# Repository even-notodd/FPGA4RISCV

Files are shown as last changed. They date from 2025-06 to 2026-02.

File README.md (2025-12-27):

# FPGA4RISCV
This project is an attempt to build hardware (SOM and baseboard) capable of runnig Linux on RISCV MCU implemented in FPGA.
## This is work in progress, not finished project (!).
Overview: 

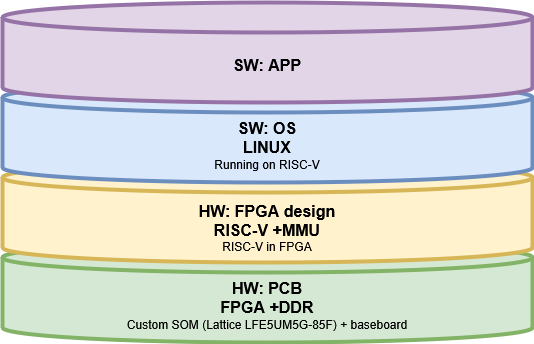
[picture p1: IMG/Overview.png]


[Edit this diagram](https://app.diagrams.net/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)

# SOM
SOM is supposed to be designed in a format of a SO-DIMM card (Small Outline Dual Inline Memory Module) with standard 200 pin board edge connector.
SoM is based on Lattice FPGA chip LFE5UM5G-85F with dedicated DDR3 memory.

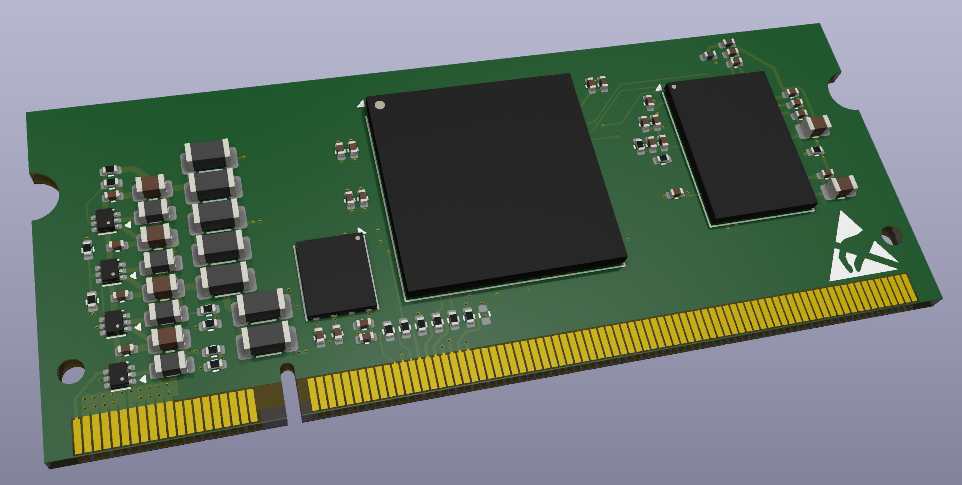
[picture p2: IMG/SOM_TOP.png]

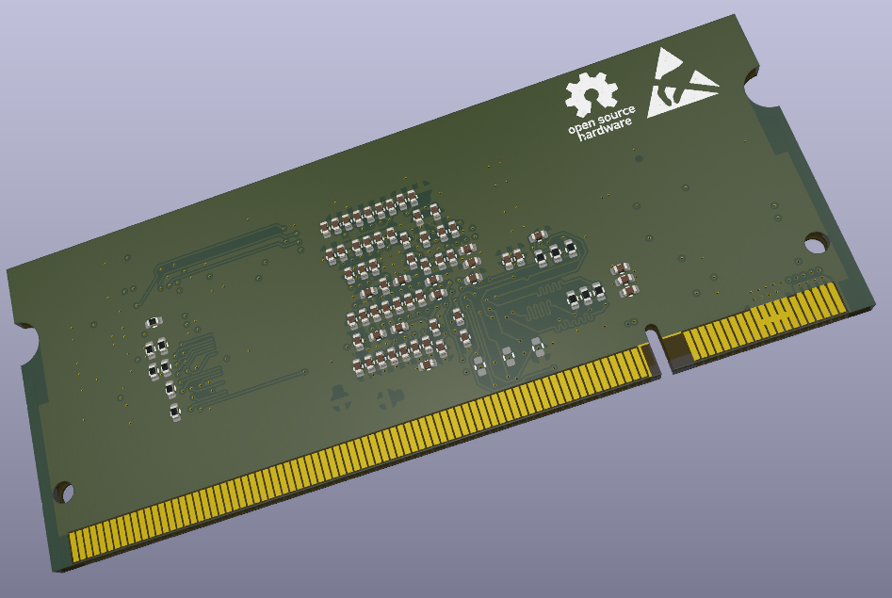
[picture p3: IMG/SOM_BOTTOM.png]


# Baseboard
Baseboard is supposed to be more or less generic baseboard and planned to be used with other SoMs. Concequently it must have:
- Power supply with several standard voltages
- Ethernet Phy
- USB 2.0 Phy & USB Hub
- USB 3.0
- PCIe
- USB-JTAG
- USB-UART
- GPIO headers
- UART/I2C/SPI headers
- HDMI

## License
See the LICENSE file for details.

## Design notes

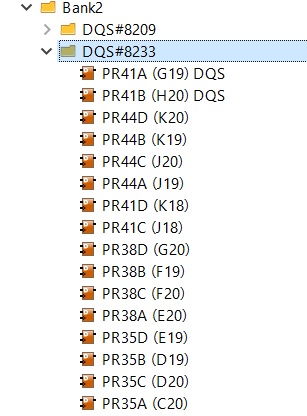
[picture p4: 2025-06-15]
IMG/DDR-Bank2.jpg

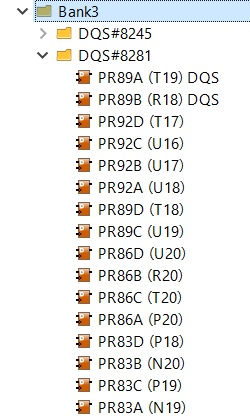
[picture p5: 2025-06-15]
IMG/DDR-Bank3.jpg

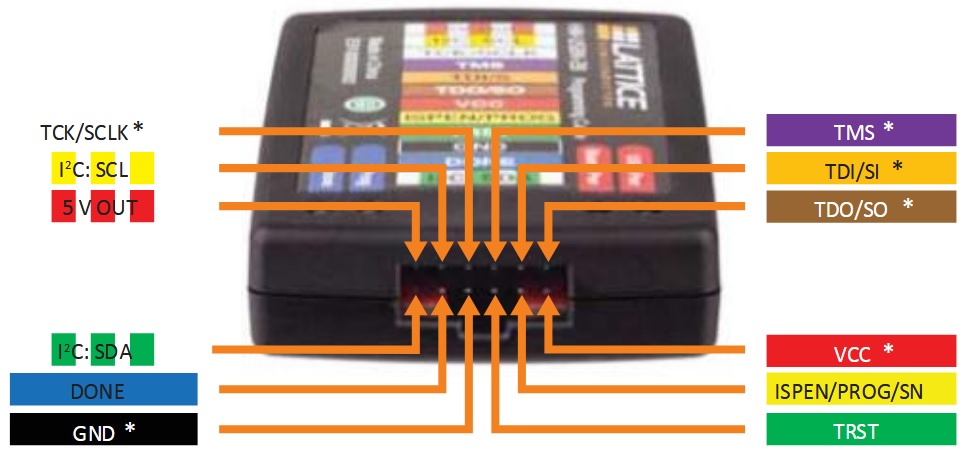
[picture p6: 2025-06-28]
IMG/Untitled.jpg

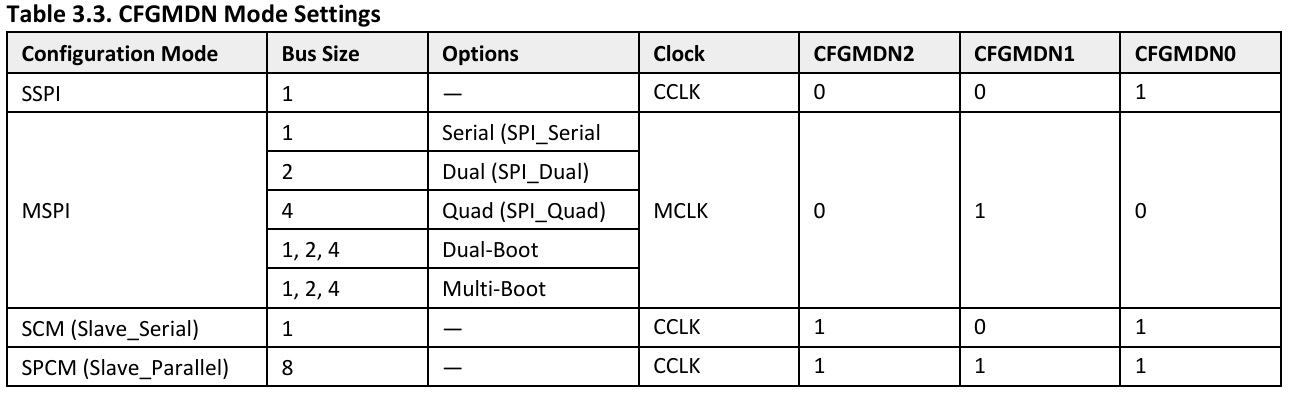
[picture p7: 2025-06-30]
IMG/Boot_CFG.jpg

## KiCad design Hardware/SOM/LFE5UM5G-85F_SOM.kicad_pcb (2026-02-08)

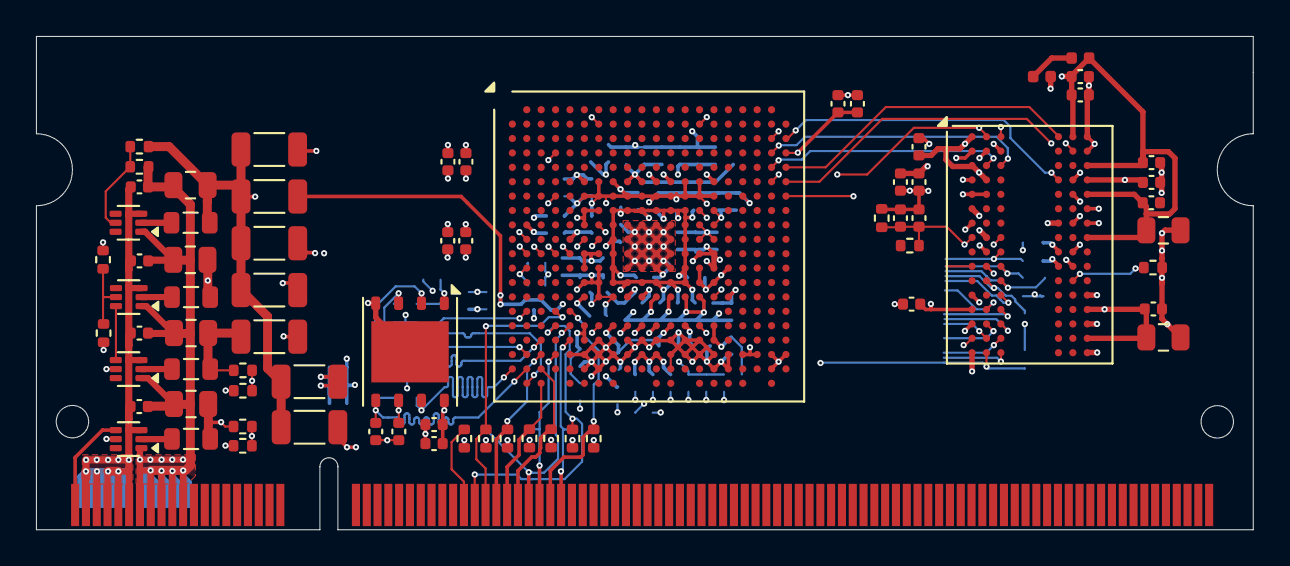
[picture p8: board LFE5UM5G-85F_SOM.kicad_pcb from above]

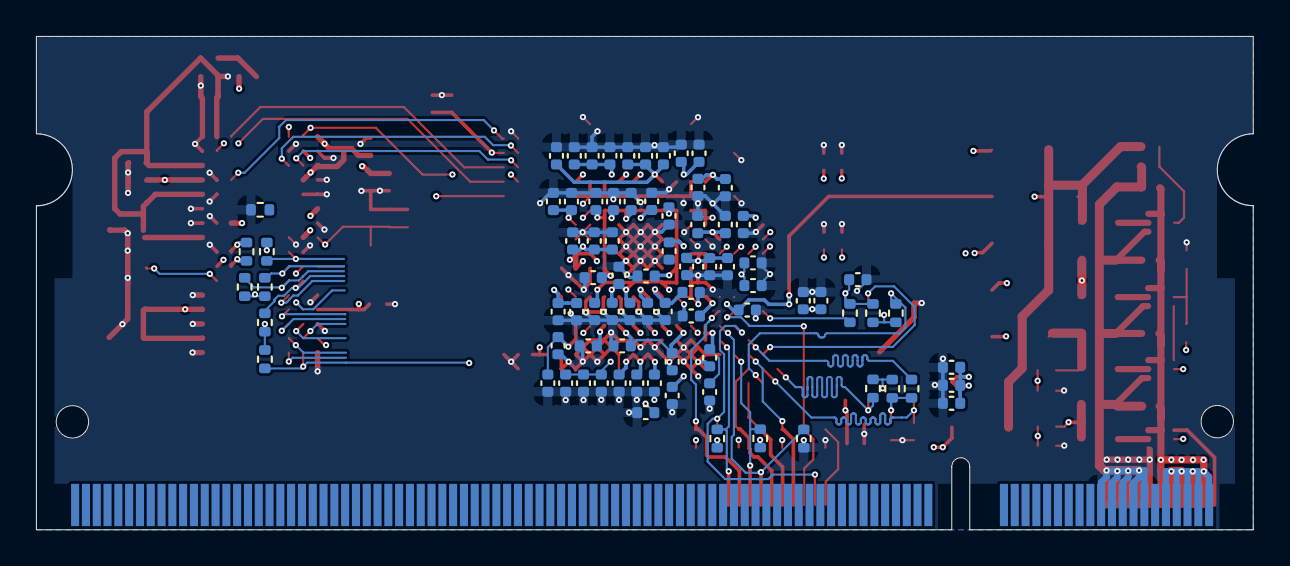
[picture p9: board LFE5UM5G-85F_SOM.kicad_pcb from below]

Board: 8 copper layers, 67.6 x 27.4 mm, 151 parts (80 on the bottom side), 94 nets.

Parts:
C1, C2, C3, C4, C5, C6, C7, C8, C9, C13, C14, C15, C17, C18, C19, C21, C22, C23, C27, C28, C30, C31, C32, C34, C46, C47, C48, C49, C50, C51, C52, C53, C54, C64, C65, C66, C67, C68, C69, C71, C73, C75, C76, C77, C84, C85, C86, C87, C89, C93: 100nF; C_0402_1005Metric
C10, C11, C12, C24, C26, C35, C36, C38, C39, C40, C41, C42, C56, C57, C58, C59, C63, C94, C95, C96, C99, C100: 10uF; C_0402_1005Metric
C43, C44, C45, C55, C60, C61, C62, C70, C72, C74, C80, C81, C82, C83, C88: 1uF; C_0402_1005Metric
C78, C79, C97, C98, C101, C102: 22uF; C_0805_2012Metric
C90, C91, C92: 22pF; C_0402_1005Metric
FB1, FB2, FB3, FB4, FB5, FB6, FB7: FerriteBead; L_1206_3216Metric
FB8, FB9: FerriteBead; L_0402_1005Metric
J1: SODIMM-200_Split; SODIMM-200_1.8V_Card_edge
L1, L2, L3, L4: 1uH; L_0805_2012Metric
R1: 100R; R_0402_1005Metric
R2, R3, R4, R5, R6, R7, R25, R26, R27, R28, R29, R30: 10K; R_0402_1005Metric
R8: 240R; R_0402_1005Metric
R9, R10: 1K; R_0402_1005Metric
R11: 49.9R; R_0402_1005Metric
R12, R14, R16: 4k7; R_0402_1005Metric
R13: 0R; R_0402_1005Metric
R15: 1k; R_0402_1005Metric
R17: 442k; R_0402_1005Metric
R18, R20, R22, R23, R24: 100K; R_0402_1005Metric
R19: 316k; R_0402_1005Metric
R21: 150k; R_0402_1005Metric
R31, R32, R33, R34: 4.7k; R_0402_1005Metric
U1: LFE5UM5G-85F; Lattice_caBGA-381_17x17mm_Layout20x20_P0.8mm
U2: AS4C256M16D3; BGA-96_9.0x13.0mm_Layout2x3x16_P0.8mm
U3: W25Q128JVP; WSON-8-1EP_6x5mm_P1.27mm_EP3.4x4.3mm
U4, U5, U6, U7: TPS62A02ADRL; SOT-563

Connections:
1.2V: C1.2, C5.2, C9.2, C13.2, C14.2, C18.2, C22.2, C23.2, C27.2, C31.2, C35.2, C39.2, C102.2, FB1.1, FB2.1, FB3.1, FB5.1, FB6.1, FB7.1, L4.2, R23.2, U1.H8 (VCC), U1.H9 (VCC), U1.H10 (VCC), U1.H11 (VCC), U1.H12 (VCC), U1.H13 (VCC), U1.J8 (VCC), U1.J13 (VCC), U1.K8 (VCC), U1.K13 (VCC), U1.L8 (VCC), U1.L13 (VCC), U1.M8 (VCC), U1.M13 (VCC), U1.N8 (VCC), U1.N9 (VCC), U1.N10 (VCC), U1.N11 (VCC), U1.N12 (VCC), U1.N13 (VCC)
1.5V: C2.2, C3.2, C4.2, C6.2, C7.2, C8.2, C10.2, C11.2, C12.2, C28.2, C32.2, C36.2, C101.2, FB8.1, FB9.1, L3.2, R9.2, R21.2, U1.F9 (VCCIO0), U1.F10 (VCCIO0), U1.H14 (VCCIO2), U1.H15 (VCCIO2), U1.J15 (VCCIO2), U1.L6 (VCCIO6), U1.L7 (VCCIO6), U1.L14 (VCCIO3), U1.L15 (VCCIO3), U1.M6 (VCCIO6), U1.M15 (VCCIO3)
2.5V: C98.2, FB4.1, L2.2, R19.2
2.5V_A: C46.2, C50.2, C54.2, C55.2, C59.2, C63.2, FB4.2, U1.F6 (VCCAUX), U1.F15 (VCCAUX), U1.P6 (VCCAUX), U1.P15 (VCCAUX), U1.V10 (VCCAUXA0), U1.V11 (VCCAUXA0), U1.V17 (VCCAUXA1), U1.V18 (VCCAUXA1)
3.3V: C15.2, C17.2, C19.2, C21.2, C24.2, C26.2, C30.2, C34.2, C38.2, C93.2, C94.2, C97.2, L1.2, R12.1, R14.1, R15.1, R16.1, R17.2, R25.1, R26.1, R27.1, R28.1, R31.2, R32.2, R33.2, U1.F11 (VCCIO1), U1.F12 (VCCIO1), U1.H6 (VCCIO7), U1.H7 (VCCIO7), U1.J6 (VCCIO7), U1.P9 (VCCIO8), U1.P10 (VCCIO8), U3.8 (VCC)
5V: C95.2, C96.2, C99.2, C100.2, J1.2, J1.3, J1.4, J1.5, J1.6, J1.7, J1.8, J1.9, J1.10, J1.11, U4.3 (VIN), U5.3 (VIN), U6.3 (VIN), U7.3 (VIN)
/DDR/ZQ: R8.1, U2.L8 (ZQ)
/Power Supply/1.5V_PG: U5.4 (EN), U6.6 (PG), U7.4 (EN)
BB_PGOOD: J1.1, U4.4 (EN), U6.4 (EN)
BOOT_MODE_0: J1.61, R30.2, U1.U4 (CFG_0)
BOOT_MODE_1: J1.63, R28.2, U1.T4 (CFG_1)
BOOT_MODE_2: J1.65, R29.2, U1.R4 (CFG_2)
DDR_A0: U1.L20 (PR47A), U2.N3 (A0)
DDR_A1: U1.M20 (PR47B), U2.P7 (A1)
DDR_A2: U1.L19 (PR47C), U2.P3 (A2)
DDR_A3: U1.M19 (PR47D), U2.N2 (A3)
DDR_A4: U1.L16 (PR50A), U2.P8 (A4)
DDR_A5: U1.L17 (PR50B), U2.P2 (A5)
DDR_A6: U1.L18 (PR50C), U2.R8 (A6)
DDR_A7: U1.M18 (PR50D), U2.R2 (A7)
DDR_A8: U1.N18 (PR53C), U2.T8 (A8)
DDR_A9: U1.P17 (PR53D), U2.R3 (A9)
DDR_A10: U1.C18 (PR11A), U2.L7 (A10/AP)
DDR_A11: U1.D17 (PR11B), U2.R7 (A11)
DDR_A12: U1.E16 (PR11C), U2.N7 (A12/~BC)
DDR_A13: U1.F16 (PR11D), U2.T3 (A13)
DDR_A14: U1.D18 (PR14A), U2.T7 (A14)
DDR_BA0: U1.E17 (PR14B), U2.M2 (BA0)
DDR_BA1: U1.E18 (PR14C), U2.N8 (BA1)
DDR_BA2: U1.F18 (PR14D), U2.M3 (BA2)
DDR_CAS: R6.1, U1.J17 (PR20C), U2.K3 (~CAS)
DDR_CKE: U1.G16 (PR17C), U2.K9 (CKE)
DDR_CK_N: R1.2, U1.G18 (PR17B), U2.K7 (~CK)
DDR_CK_P: R1.1, U1.F17 (PR17A), U2.J7 (CK)
DDR_CS: R4.1, U1.H18 (PR20A), U2.L2 (~CS)
DDR_DQ0: U1.N19 (PR83A), U2.E3 (DQ0)
DDR_DQ1: U1.N20 (PR83B), U2.F7 (DQ1)
DDR_DQ2: U1.P19 (PR83C), U2.F2 (DQ2)
DDR_DQ3: U1.P18 (PR83D), U2.F8 (DQ3)
DDR_DQ4: U1.P20 (PR86A), U2.H3 (DQ4)
DDR_DQ5: U1.R20 (PR86B), U2.H8 (DQ5)
DDR_DQ6: U1.T20 (PR86C), U2.G2 (DQ6)
DDR_DQ7: U1.U20 (PR86D), U2.H7 (DQ7)
DDR_DQ8: U1.C20 (PR35A), U2.D7 (DQ8)
DDR_DQ9: U1.D19 (PR35B), U2.C3 (DQ9)
DDR_DQ10: U1.K18 (PR41D), U2.C8 (DQ10)
DDR_DQ11: U1.E19 (PR35D), U2.C2 (DQ11)
DDR_DQ12: U1.E20 (PR38A), U2.A7 (DQ12)
DDR_DQ13: U1.F19 (PR38B), U2.A2 (DQ13)
DDR_DQ14: U1.F20 (PR38C), U2.B8 (DQ14)
DDR_DQ15: U1.G20 (PR38D), U2.A3 (DQ15)
DDR_LDM: U1.U19 (PR89C), U2.E7 (LDM)
DDR_LDQS_N: U1.R18 (PR89B), U2.G3 (~LDQS)
DDR_LDQS_P: U1.T19 (PR89A), U2.F3 (LDQS)
DDR_ODT: R2.1, U1.K16 (PR29A), U2.K1 (ODT)
DDR_RAS: R5.1, U1.H17 (PR20B), U2.J3 (~RAS)
DDR_RST: R3.1, U1.H16 (PR17D), U2.T2 (~RESET)
DDR_UDM: U1.J18 (PR41C), U2.D3 (UDM)
DDR_UDQS_N: U1.H20 (PR41B), U2.B7 (~UDQS)
DDR_UDQS_P: U1.G19 (PR41A), U2.C7 (UDQS)
DDR_VDDQ_1.5V: C76.2, C78.2, C80.2, C82.2, C84.2, C86.2, FB8.2, U2.A1 (VDDQ), U2.A8 (VDDQ), U2.C1 (VDDQ), U2.C9 (VDDQ), U2.D2 (VDDQ), U2.E9 (VDDQ), U2.F1 (VDDQ), U2.H2 (VDDQ), U2.H9 (VDDQ)
DDR_VDD_1.5V: C77.2, C79.2, C81.2, C83.2, C85.2, C87.2, FB9.2, R3.2, R4.2, R5.2, R6.2, R7.2, U2.B2 (VDD), U2.D9 (VDD), U2.G7 (VDD), U2.K2 (VDD), U2.K8 (VDD), U2.N1 (VDD), U2.N9 (VDD), U2.R1 (VDD), U2.R9 (VDD)
DDR_VREF: C70.2, C71.2, C72.2, C73.2, C74.2, C75.2, C88.2, C89.2, R9.1, R10.2, U1.D20 (PR35C), U1.K5 (PL56B), U1.P16 (PR56B), U2.H1 (VREFDQ), U2.M8 (VREFCA)
DDR_WE: R7.1, U1.J16 (PR20D), U2.L3 (~WE)
DONE: J1.69, R27.2, U1.Y3 (DONE)
GND: C1.1, C2.1, C3.1, C4.1, C5.1, C6.1, C7.1, C8.1, C9.1, C10.1, C11.1, C12.1, C13.1, C14.1, C15.1, C17.1, C18.1, C19.1, C21.1, C22.1, C23.1, C24.1, C26.1, C27.1, C28.1, C30.1, C31.1, C32.1, C34.1, C35.1, C36.1, C38.1, C39.1, C40.1, C41.1, C42.1, C43.1, C44.1, C45.1, C46.1, C47.1, C48.1, C49.1, C50.1, C51.1, C52.1, C53.1, C54.1, C55.1, C56.1, C57.1, C58.1, C59.1, C60.1, C61.1, C62.1, C63.1, C64.1, C65.1, C66.1, C67.1, C68.1, C69.1, C70.1, C71.1, C72.1, C73.1, C74.1, C75.1, C76.1, C77.1, C78.1, C79.1, C80.1, C81.1, C82.1, C83.1, C84.1, C85.1, C86.1, C87.1, C88.1, C89.1, C90.2, C91.2, C92.2, C93.1, C94.1, C95.1, C96.1, C97.1, C98.1, C99.1, C100.1, C101.1, C102.1, J1.13, J1.14, J1.15, J1.16, J1.17, J1.18, J1.19, J1.20, J1.21, J1.22, R2.2, R8.2, R10.1, R18.1, R20.1, R22.1, R24.1, R29.1, R30.1, R34.2, U1.B7 (GND), U1.B14 (GND), U1.C19 (GND), U1.D4 (GND), U1.F7 (GND), U1.F8 (GND), U1.F13 (GND), U1.F14 (GND), U1.G4 (GND), U1.G6 (GND), U1.G7 (GND), U1.G8 (GND), U1.G9 (GND), U1.G10 (GND), U1.G11 (GND), U1.G12 (GND), U1.G13 (GND), U1.G14 (GND), U1.G15 (GND), U1.G17 (GND), U1.H19 (GND), U1.J2 (GND), U1.J7 (GND), U1.J9 (GND), U1.J10 (GND), U1.J11 (GND), U1.J12 (GND), U1.J14 (GND), U1.K6 (GND), U1.K7 (GND), U1.K9 (GND), U1.K10 (GND), U1.K11 (GND), U1.K12 (GND), U1.K14 (GND), U1.K15 (GND), U1.L9 (GND), U1.L10 (GND), U1.L11 (GND), U1.L12 (GND), U1.M2 (GND), U1.M7 (GND), U1.M9 (GND), U1.M10 (GND), U1.M11 (GND), U1.M12 (GND), U1.M14 (GND), U1.M16 (GND), U1.N6 (GND), U1.N7 (GND), U1.N14 (GND), U1.N15 (GND), U1.P7 (GND), U1.P8 (GND), U1.P11 (GND), U1.P12 (GND), U1.P13 (GND), U1.P14 (GND), U1.R19 (GND), U1.U7 (GND), U1.U8 (GND), U1.U9 (GND), U1.U10 (GND), U1.U11 (GND), U1.U12 (GND), U1.U13 (GND), U1.U14 (GND), U1.V5 (GND), U1.V6 (GND), U1.V7 (GND), U1.V8 (GND), U1.V9 (GND), U1.V12 (GND), U1.V13 (GND), U1.V14 (GND), U1.V15 (GND), U1.V16 (GND), U1.V19 (GND), U1.V20 (GND), U1.W6 (GND), U1.W7 (GND), U1.W12 (GND), U1.W15 (GND), U1.W16 (GND), U1.W19 (GND), U2.A9 (VSS), U2.B1 (VSSQ), U2.B3 (VSS), U2.B9 (VSSQ), U2.D1 (VSSQ), U2.D8 (VSSQ), U2.E1 (VSS), U2.E2 (VSSQ), U2.E8 (VSSQ), U2.F9 (VSSQ), U2.G1 (VSSQ), U2.G8 (VSS), U2.G9 (VSSQ), U2.J2 (VSS), U2.J8 (VSS), U2.M1 (VSS), U2.M9 (VSS), U2.P1 (VSS), U2.P9 (VSS), U2.T1 (VSS), U2.T9 (VSS), U3.4 (GND), U3.9 (EP), U4.1 (GND), U5.1 (GND), U6.1 (GND), U7.1 (GND)
INIT#: J1.67, R26.2, U1.V3 (~INIT)
JTAG_TCK: J1.73, R34.1, U1.T5 (TCK)
JTAG_TDI: J1.77, R32.1, U1.R5 (TDI)
JTAG_TDO: J1.75, R31.1, U1.V4 (TDO)
JTAG_TMS: J1.79, R33.1, U1.U5 (TMS)
unnamed: C91.1, R11.1, R15.2, U3.6 (CLK)
unnamed: C90.1, R13.1, R16.2, U3.1 (~CS)
unnamed: R17.1, R18.2, U4.5 (FB)
unnamed: L1.1, U4.2 (SW)
unnamed: R19.1, R20.2, U5.5 (FB)
unnamed: L2.1, U5.2 (SW)
unnamed: R21.1, R22.2, U6.5 (FB)
unnamed: L3.1, U6.2 (SW)
unnamed: R23.1, R24.2, U7.5 (FB)
unnamed: L4.1, U7.2 (SW)
PROGRAM#: J1.71, R25.2, U1.W3 (~PROGRAM)
QSPI_CLK: R11.2, U1.U3 (CCLK)
QSPI_CS: R13.2, U1.R2 (PB15A)
QSPI_MISO/DQ1: U1.V2 (PB11A), U3.2 (DO/IO_{1})
QSPI_MOSI/DQ0: C92.1, U1.W2 (PB11B), U3.5 (DI/IO_{0})
QSPI_RST/DQ3: R12.2, U1.W1 (PB9A), U3.7 (~HOLD/~RESET/IO_{3})
QSPI_WP/DQ2: R14.2, U1.Y2 (PB9B), U3.3 (~WP/IO_{2})
VCCA0: C40.2, C43.2, C47.2, C51.2, FB1.2, U1.T6 (VCCA0), U1.U6 (VCCA0)
VCCA1: C56.2, C60.2, C64.2, C67.2, FB5.2, U1.T15 (VCCA1), U1.U15 (VCCA1)
VCCHTX0: C41.2, C44.2, C48.2, C52.2, FB2.2, U1.T7 (VCCHTX0_D0CH0), U1.T11 (VCCHTX0_D1CH0)
VCCHTX1: C57.2, C61.2, C65.2, C68.2, FB6.2, U1.T10 (VCCHTX1_D0CH1), U1.T14 (VCCHTX1_D1CH1)
VCC_SER_0: C42.2, C45.2, C49.2, C53.2, FB3.2, U1.T8 (VCCHRX0_D0CH0), U1.T12 (VCCHRX0_D1CH0)
VCC_SER_1: C58.2, C62.2, C66.2, C69.2, FB7.2, U1.T9 (VCCHRX1_D0CH1), U1.T13 (VCCHRX1_D1CH1)

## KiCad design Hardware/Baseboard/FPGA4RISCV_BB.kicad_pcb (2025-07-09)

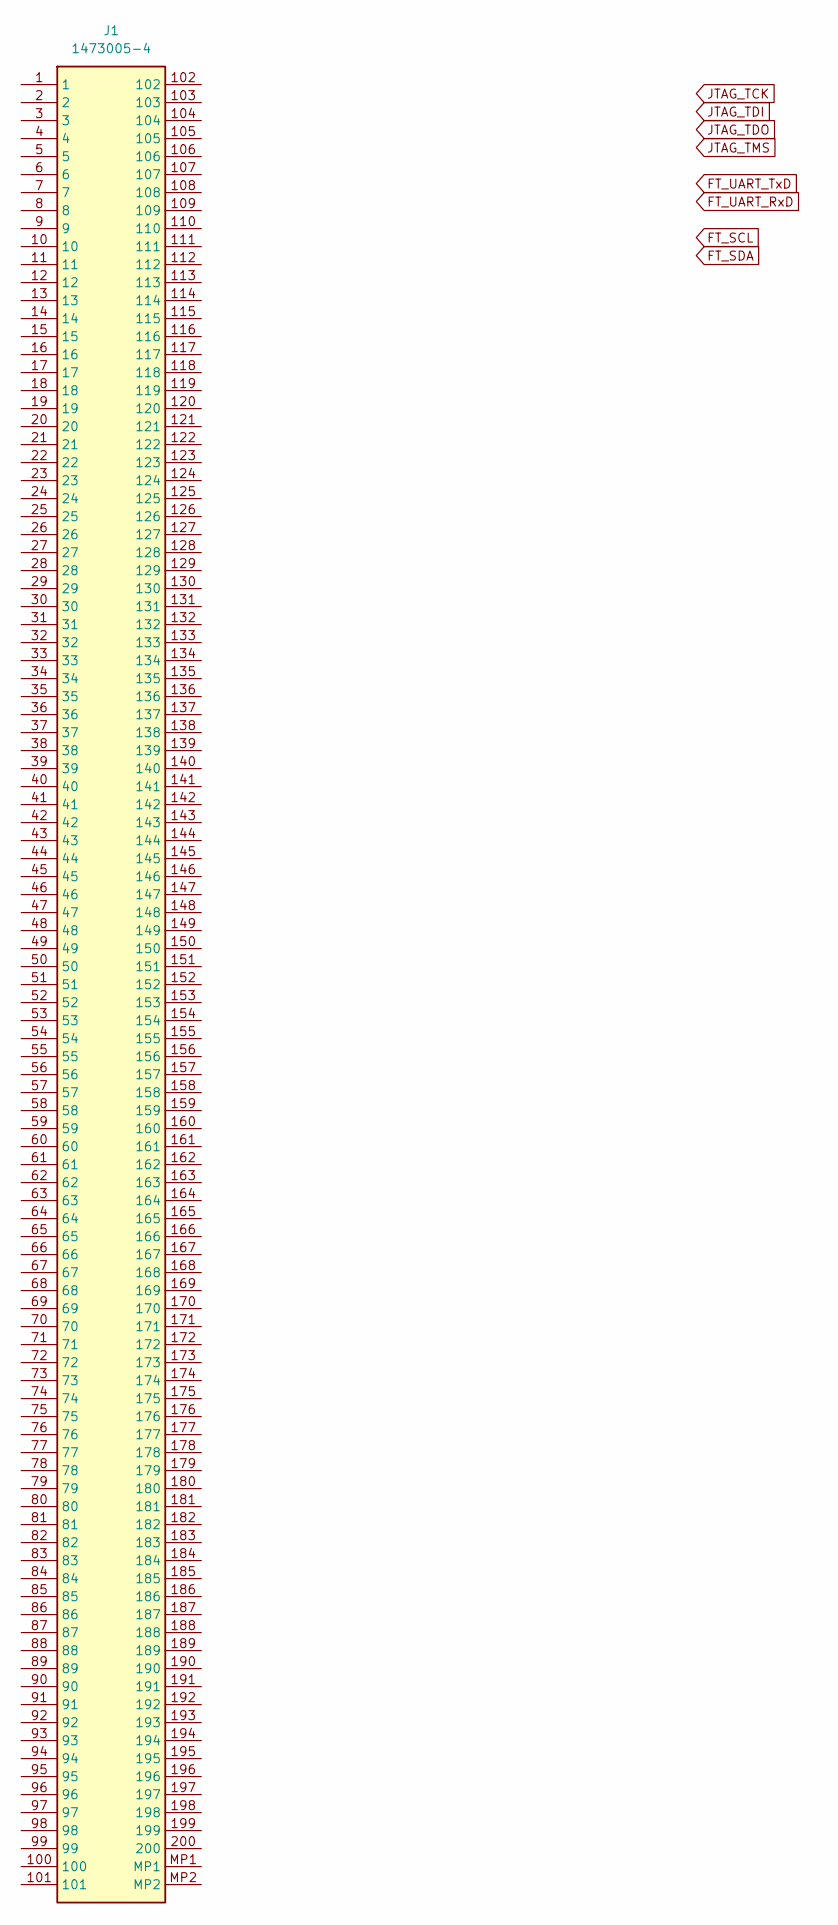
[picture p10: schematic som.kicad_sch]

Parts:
J1: 1473005-4; 14730054; Mouser Part Number 571-1473005-4

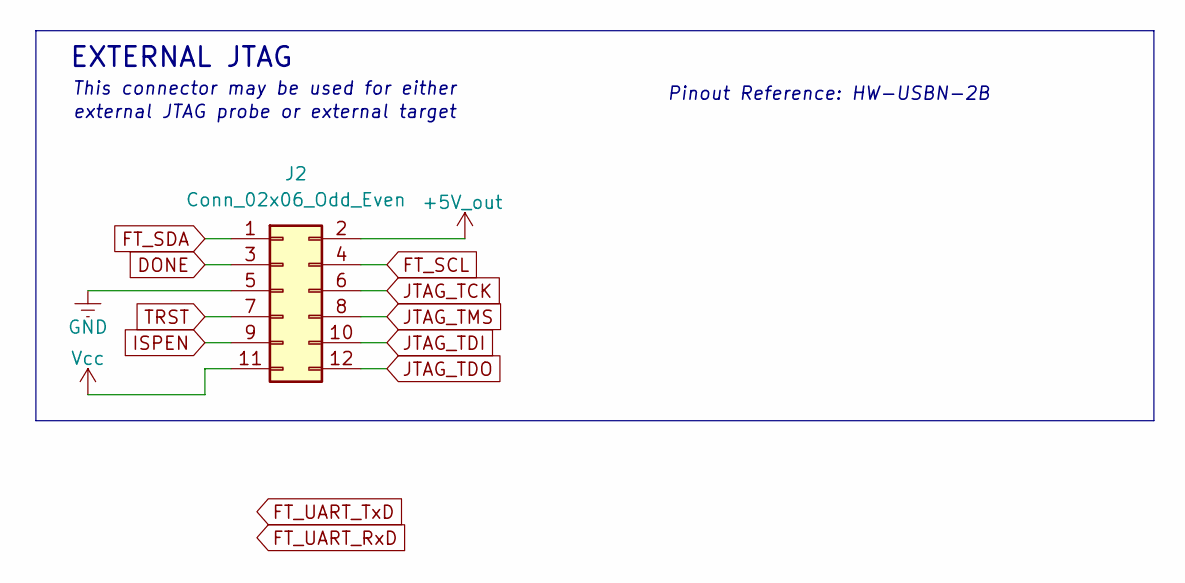
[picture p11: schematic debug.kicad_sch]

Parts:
J2: Conn_02x06_Odd_Even; PinHeader_2x06_P2.54mm_Vertical

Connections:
+5V_out: J2.2
DONE: J2.3
FT_SCL: J2.4; also elsewhere on the board
FT_SDA: J2.1; also elsewhere on the board
GND: J2.5; also elsewhere on the board
ISPEN: J2.9
JTAG_TCK: J2.6; also elsewhere on the board
JTAG_TDI: J2.10; also elsewhere on the board
JTAG_TDO: J2.12; also elsewhere on the board
JTAG_TMS: J2.8; also elsewhere on the board
TRST: J2.7
Vcc: J2.11

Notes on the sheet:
external JTAG probe or external target
Pinout Reference: HW-USBN-2B
EXTERNAL JTAG
This connector may be used for either

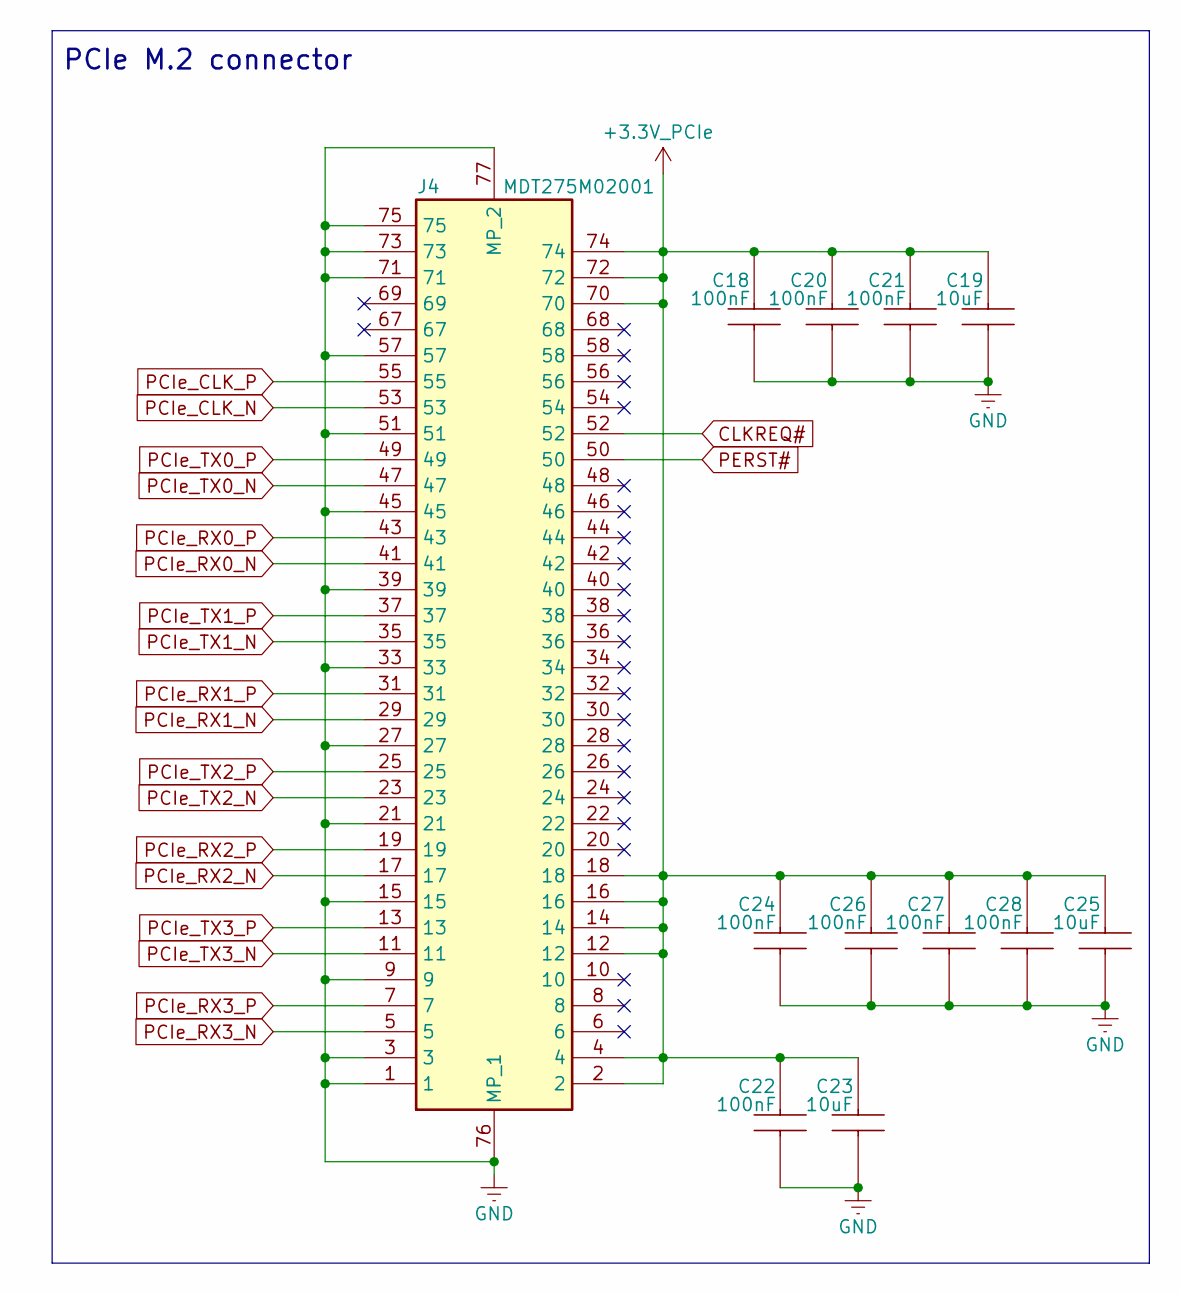
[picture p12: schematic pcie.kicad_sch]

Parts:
C18, C20, C21, C22, C24, C26, C27, C28: 100nF; C_0402_1005Metric; MPN 885012205092
C19, C23, C25: 10uF; C_0402_1005Metric; MPN 885012105020
J4: MDT275M02001; Mouser Part Number 523-MDT275M02001

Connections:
+3.3V_PCIe: C18.2, C19.2, C20.2, C21.2, C22.2, C23.2, C24.2, C25.2, C26.2, C27.2, C28.2, J4.2, J4.4, J4.12, J4.14, J4.16, J4.18, J4.70, J4.72, J4.74
CLKREQ#: J4.52
GND: C18.1, C19.1, C20.1, C21.1, C22.1, C23.1, C24.1, C25.1, C26.1, C27.1, C28.1, J4.1, J4.3, J4.9, J4.15, J4.21, J4.27, J4.33, J4.39, J4.45, J4.51, J4.57, J4.71, J4.73, J4.75, J4.76 (MP_1), J4.77 (MP_2); also elsewhere on the board
PCIe_CLK_N: J4.53
PCIe_CLK_P: J4.55
PCIe_RX0_N: J4.41
PCIe_RX0_P: J4.43
PCIe_RX1_N: J4.29
PCIe_RX1_P: J4.31
PCIe_RX2_N: J4.17
PCIe_RX2_P: J4.19
PCIe_RX3_N: J4.5
PCIe_RX3_P: J4.7
PCIe_TX0_N: J4.47
PCIe_TX0_P: J4.49
PCIe_TX1_N: J4.35
PCIe_TX1_P: J4.37
PCIe_TX2_N: J4.23
PCIe_TX2_P: J4.25
PCIe_TX3_N: J4.11
PCIe_TX3_P: J4.13
PERST#: J4.50

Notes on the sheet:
PCIe M.2 connector

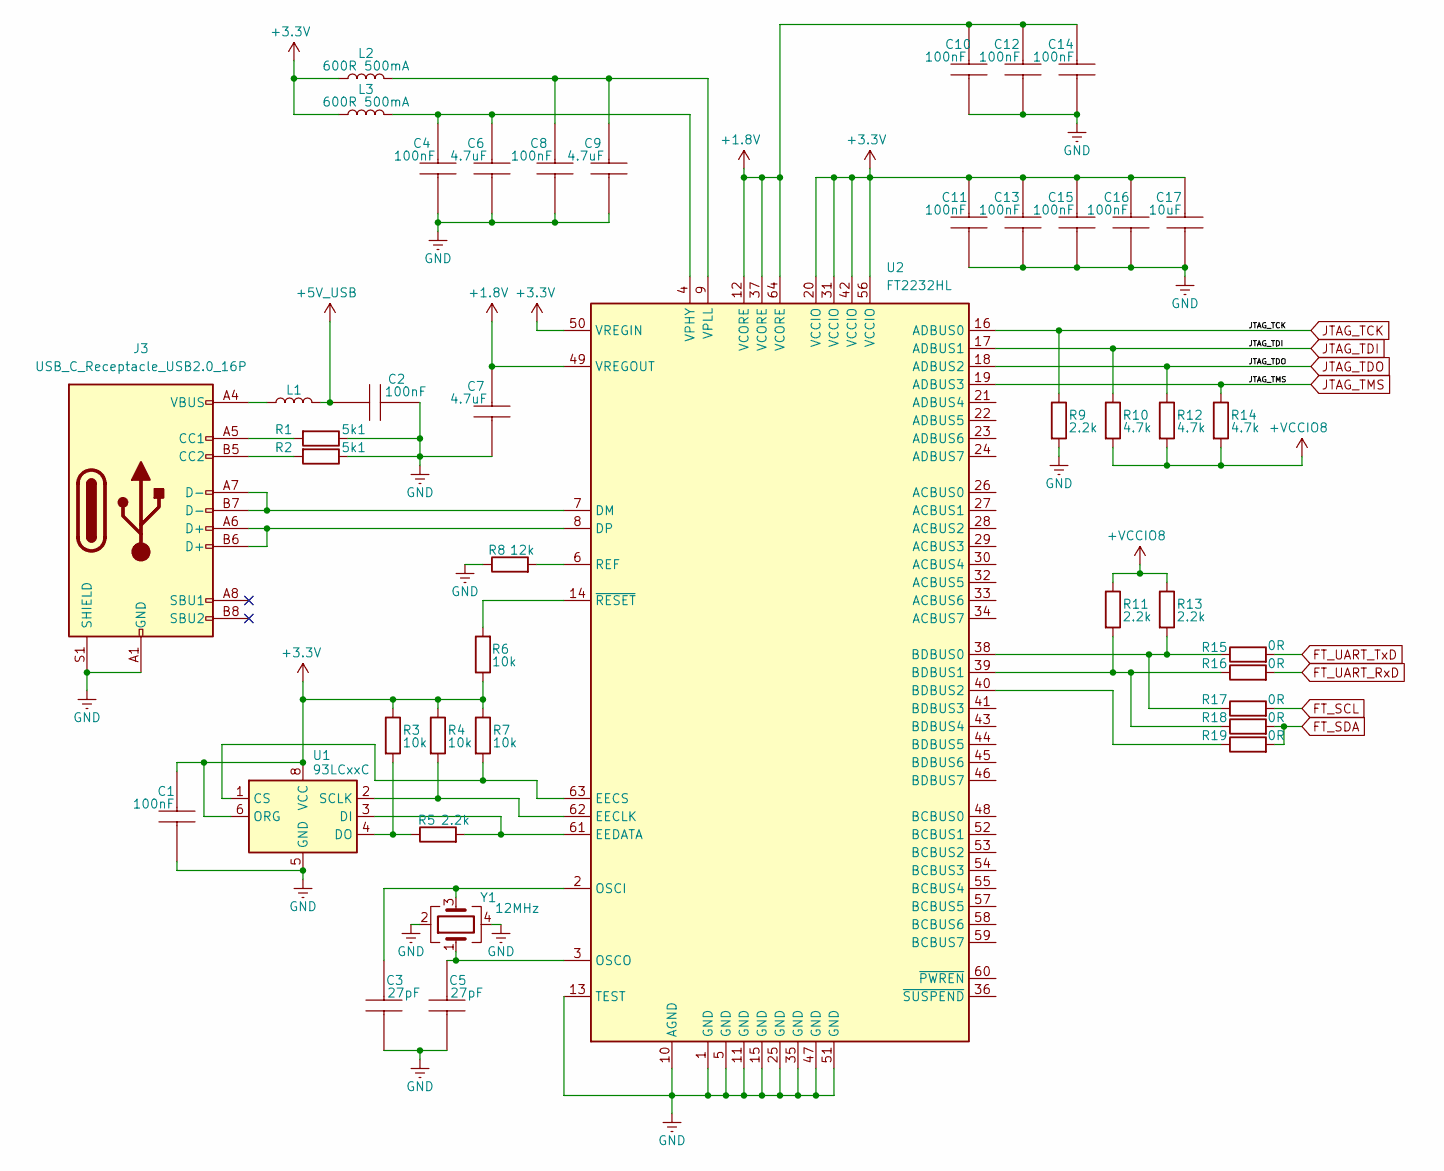
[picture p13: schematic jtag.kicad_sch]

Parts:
C1, C2, C4, C8, C10, C11, C12, C13, C14, C15, C16: 100nF; C_0402_1005Metric; MPN 885012205092
C3, C5: 27pF; C_0402_1005Metric; MPN 885392005116
C6, C7, C9: 4.7uF; C_0402_1005Metric; MPN 885012105008
C17: 10uF; C_0402_1005Metric; MPN 885012105020
J3: USB_C_Receptacle_USB2.0_16P; USB_C_Receptacle_GCT_USB4110; MPN USB4110-GF-A
L1, L2, L3: 600R 500mA; MPN 560112110245
R1, R2: 5k1; R_0402_1005Metric; MPN 560112120019
R3, R4, R6, R7: 10k; R_0402_1005Metric; MPN 560112110020
R5, R9, R11, R13: 2.2k; R_0402_1005Metric; MPN 560112110087
R8: 12k; R_0402_1005Metric; MPN 560112116040
R10, R12, R14: 4.7k; R_0402_1005Metric; MPN 560112110245
R15, R16, R17, R18, R19: 0R; R_0402_1005Metric; MPN 560112110087
U1: 93LCxxC
U2: FT2232HL; LQFP-64_10x10mm_P0.5mm
Y1: 12MHz; Crystal_SMD_3225-4Pin_3.2x2.5mm; MPN ABM8-12.000MHZ-D4H-T

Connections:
+1.8V: C7.2, C10.2, C12.2, C14.2, U2.12 (VCORE), U2.37 (VCORE), U2.49 (VREGOUT), U2.64 (VCORE)
+3.3V: C1.2, C11.2, C13.2, C15.2, C16.2, C17.2, L2.1, L3.1, R3.1, R4.1, R6.1, R7.1, U1.6 (ORG), U1.8 (VCC), U2.20 (VCCIO), U2.31 (VCCIO), U2.42 (VCCIO), U2.50 (VREGIN), U2.56 (VCCIO)
+5V_USB: C2.1, L1.2
+VCCIO8: R10.2, R11.1, R12.2, R13.1, R14.2
FT_SCL: R17.2; also elsewhere on the board
FT_SDA: R18.2, R19.2; also elsewhere on the board
FT_UART_RxD: R16.2
FT_UART_TxD: R15.2
GND: C1.1, C2.2, C3.1, C4.1, C5.1, C6.1, C7.1, C8.1, C9.1, C10.1, C11.1, C12.1, C13.1, C14.1, C15.1, C16.1, C17.1, J3.A1 (GND), J3.A12 (GND), J3.B1 (GND), J3.B12 (GND), J3.S1 (SHIELD), R1.1, R2.1, R8.1, R9.2, U1.5 (GND), U2.1 (GND), U2.5 (GND), U2.10 (AGND), U2.11 (GND), U2.13 (TEST), U2.15 (GND), U2.25 (GND), U2.35 (GND), U2.47 (GND), U2.51 (GND), Y1.2, Y1.4; also elsewhere on the board
JTAG_TCK: R9.1, U2.16 (ADBUS0); also elsewhere on the board
JTAG_TDI: R10.1, U2.17 (ADBUS1); also elsewhere on the board
JTAG_TDO: R12.1, U2.18 (ADBUS2); also elsewhere on the board
JTAG_TMS: R14.1, U2.19 (ADBUS3); also elsewhere on the board
unnamed: J3.A5 (CC1), R1.2
unnamed: J3.B5 (CC2), R2.2
unnamed: J3.A4 (VBUS), J3.A9 (VBUS), J3.B4 (VBUS), J3.B9 (VBUS), L1.1
unnamed: R7.2, U1.1 (CS), U2.63 (EECS)
unnamed: R5.2, U1.3 (DI), U2.61 (EEDATA)
unnamed: R3.2, R5.1, U1.4 (DO)
unnamed: R4.2, U1.2 (SCLK), U2.62 (EECLK)
unnamed: R13.2, R15.1, R17.1, U2.38 (BDBUS0)
unnamed: R11.2, R16.1, R18.1, U2.39 (BDBUS1)
unnamed: R19.1, U2.40 (BDBUS2)
unnamed: J3.A7 (D-), J3.B7 (D-), U2.7 (DM)
unnamed: J3.A6 (D+), J3.B6 (D+), U2.8 (DP)
unnamed: C3.2, U2.2 (OSCI), Y1.3
unnamed: C5.2, U2.3 (OSCO), Y1.1
unnamed: R8.2, U2.6 (REF)
unnamed: C4.2, C6.2, L3.2, U2.4 (VPHY)
unnamed: C8.2, C9.2, L2.2, U2.9 (VPLL)
unnamed: R6.2, U2.14 (~RESET)

Board: 2 copper layers, 53 parts (0 on the bottom side), 29 nets, no tracks yet.

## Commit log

2025-06-09 Init Kicad projects
    [FPGA4RISCV_BB.kicad_pcb, FPGA4RISCV_BB.kicad_sch, LFE5UM5G-85F_SOM.kicad_pcb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]
2025-06-09 SOM: +DDR IC
    [LFE5UM5G-85F_SOM.kicad_sch, ddr.kicad_sch, io.kicad_sch]
2025-06-09 SOM: SO-DIMM connector
    [Connector.kicad_sch, FPGA.kicad_sch, LFE5UM5G-85F_SOM.kicad_pcb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]
2025-06-14 SOM board outline
    [FPGA4RISCV_BB.kicad_sch, LFE5UM5G-85F_SOM.kicad_pcb, LFE5UM5G-85F_SOM.kicad_sch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]
2025-06-14 BB SOM connector
    [Connector.kicad_sch, LFE5UM5G-85F_SOM.kicad_pcb, som.kicad_sch]
2025-06-15 SOM: DDR schematics update
    [DBG.kicad_sch, FPGA.kicad_sch, LFE5UM5G-85F_SOM.kicad_pcb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]
2025-06-15 some schematics update
    [FPGA.kicad_sch, jtag.kicad_sch]
2025-06-15 SOM layout fix
    [LFE5UM5G-85F_SOM.kicad_pcb]
2025-06-23 Baseboard: JTAG
    [jtag.kicad_sch]
2025-06-28 QSPI, banks IO decoupling
    [Connector.kicad_sch, FPGA.kicad_sch, FPGA4RISCV_BB.kicad_sch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]
2025-06-29 QSPI connected
    [FPGA.kicad_sch, QSPI.kicad_sch]
2025-06-29 DDR-FPGA connection
    [FPGA.kicad_sch]
2025-06-29 DDR clock termination
    [FPGA.kicad_sch, ddr.kicad_sch]
2025-06-29 ZQ calibration resistor added
    [FPGA.kicad_sch, ddr.kicad_sch]
2025-06-30 SOM: Boot mode CFG
    [Connector.kicad_sch, FPGA.kicad_sch, ddr.kicad_sch]
2025-07-01 SOM: DDR pull-ups
    [FPGA.kicad_sch, QSPI.kicad_sch, ddr.kicad_sch]
2025-07-04 DDR Banks Vref
    [Connector.kicad_sch, DBG.kicad_sch, FPGA.kicad_sch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]
2025-07-08 M.2 connector added
    [FPGA4RISCV_BB.kicad_sch, debug.kicad_sch, jtag.kicad_sch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]
2025-07-09 PCIe M.2 connector changed
    [FPGA4RISCV_BB.kicad_pcb, LFE5UM5G-85F_SOM.kicad_pcb, debug.kicad_sch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]
2025-07-09 BB: PCIe update
    [FPGA4RISCV_BB.kicad_pcb, jtag.kicad_sch, pcie.kicad_sch]
2025-07-10 PCIe AC coupling
    [Interfaces.kicad_sch, LFE5UM5G-85F_SOM.kicad_sch, PS.kicad_sch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]
2025-07-12 PCIe M.2 pull-ups
    [pcie.kicad_sch, som.kicad_sch]
2025-07-13 SOM: power supplies
    [DBG.kicad_sch, FPGA.kicad_sch, PS.kicad_sch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]
2025-07-13 SOM: power supply update
    [Connector.kicad_sch, DBG.kicad_sch, FPGA.kicad_sch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]
2025-07-14 SOM: Serdes power
    [FPGA.kicad_sch]
2025-07-21 SOM: components placement
    [LFE5UM5G-85F_SOM.kicad_pcb]
2025-08-10 SOM: layout update
    [Connector.kicad_sch, DBG.kicad_sch, FPGA.kicad_sch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]
2025-08-13 SOM: QSPI layout update
    [LFE5UM5G-85F_SOM.kicad_pcb]
2025-08-13 SOM: layout update (QSPI+
    [Connector.kicad_sch, FPGA.kicad_sch, LFE5UM5G-85F_SOM.kicad_pcb]
2025-12-09 SOM stack-up JLC06161H-3313
    [FPGA.kicad_sch, LFE5UM5G-85F_SOM.kicad_pcb]
2025-12-09 Switched to 8-layer stack-up JLC08161H-2116
    [LFE5UM5G-85F_SOM.kicad_pcb, LFE5UM5G-85F_SOM.kicad_sch]
2025-12-11 some net names added
    [FPGA.kicad_sch, LFE5UM5G-85F_SOM.kicad_pcb]
2025-12-23 SOM: decoupling caps placement
    [FPGA.kicad_sch, LFE5UM5G-85F_SOM.kicad_pcb]
2025-12-23 SOM: more caps moved to their place
    [LFE5UM5G-85F_SOM.kicad_pcb]
2025-12-24 Decopuling placement continued
    [LFE5UM5G-85F_SOM.kicad_pcb]
2025-12-25 DDR clock schematics fixed
    [FPGA.kicad_sch, LFE5UM5G-85F_SOM.kicad_pcb, ddr.kicad_sch]
2026-01-10 DDR reconnect
    [DBG.kicad_sch, FPGA.kicad_sch, LFE5UM5G-85F_SOM.kicad_pcb]
2026-01-12 BB schematics: PS
    [jtag.kicad_sch, ps.kicad_sch]
2026-01-13 lic file update
    [ps.kicad_sch]
2026-02-08 SOM: DDR PWR UPD
    [LFE5UM5G-85F_SOM.kicad_pcb, ddr.kicad_sch]
